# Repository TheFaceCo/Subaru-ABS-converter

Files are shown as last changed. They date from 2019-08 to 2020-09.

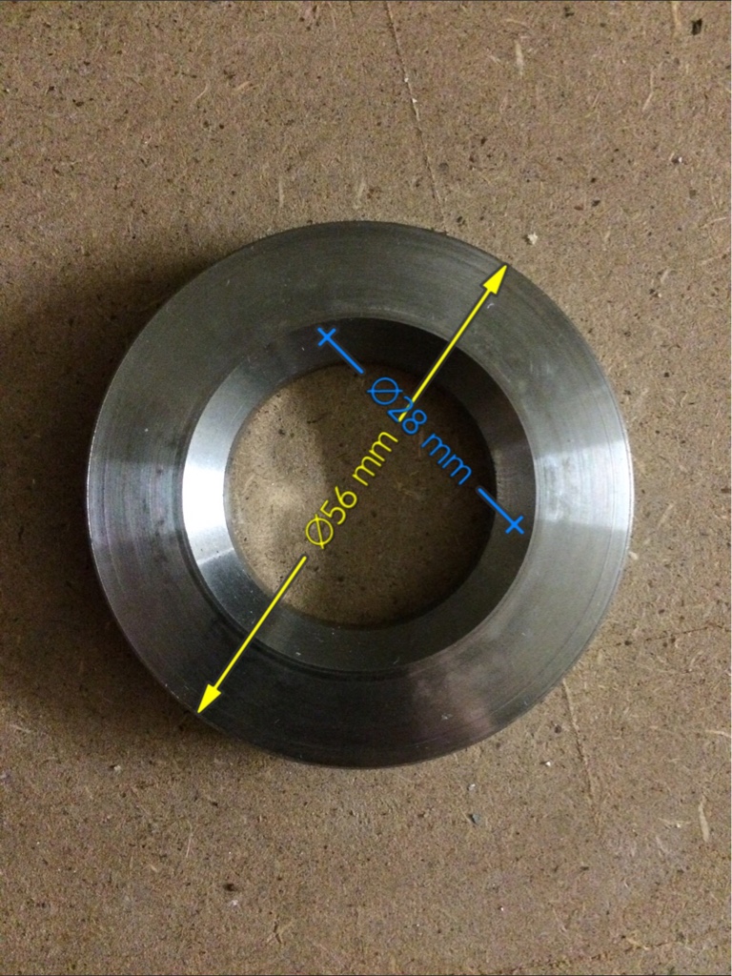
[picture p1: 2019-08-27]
Docs/e455d0daeaaa72b5a07195fe7253229a.jpg

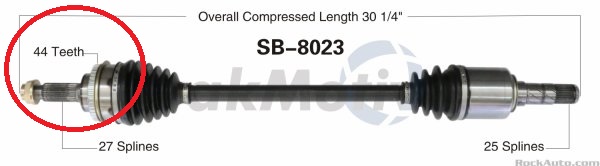
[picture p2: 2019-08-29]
Docs/SB-8023__ra_p.jpg

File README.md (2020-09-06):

# Subaru-ABS-converter
Read hall sensors, output variable reluctance (VR) sensors.

This converts modern hall sensor inputs to older VR outputs using a Maxim 9921 IC to read 2-wire hall sensors with a Teensy 3.2. 
Use this device if you are installing new hubs that use hall wheel speed sensors on old cars with variable reluctance ABS tone-rings.

The output stage is a 2-bit digital output fed to an audio transformer (1:1 600ohm:600ohm). 
The transformer removes the DC bias and presents an inductive source to the OEM ABS inputs (to circumvent open- or short-circuit error detection).

Set the input wheel tooth count to the OEM VR wheel tooth count. 

Set the output wheel tooth count to 2x the number of magnetic poles (count poles using magentic film, see image of subaru encoder). 
The Max9921 counts both the rising and falling edge of each magnetic pole, hence the multiplier.

Set Teensy clock to 24MHz to reduce thermal issues. CPU may freeze at high temperatures. First suspect for stability problems is the crystal oscillator. 

This also includes a generic digital output labeled "VSS". This allows the device to present a VSS signal calculated as the average of both inputs.
The VSS output can be used to provide a VSS signal in the case of a new transmission without a built-in VSS sensor.
The VSS output, as installed in my car, just drives an LED and is used for status reporting. This needs to be modified if you want a proper VSS output.

There is an additional op-amp stage, but this has been left un-routed due to pure laziness. 

This setup produces and unknown amount of jitter, but it should be relatively small. 

Outputs will be disabled by >1 error per 10 seconds in the default config. 

Be sure to cut the USB power trace on the teensy prior to soldering to the board.

Use at your own risk.

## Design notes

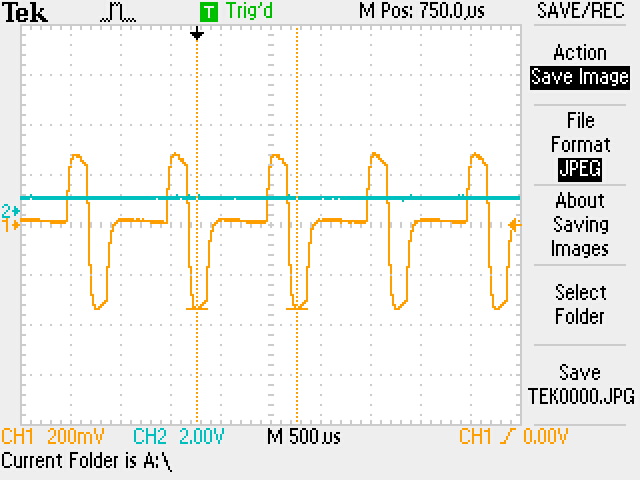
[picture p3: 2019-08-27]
Docs/TEK0000.JPG

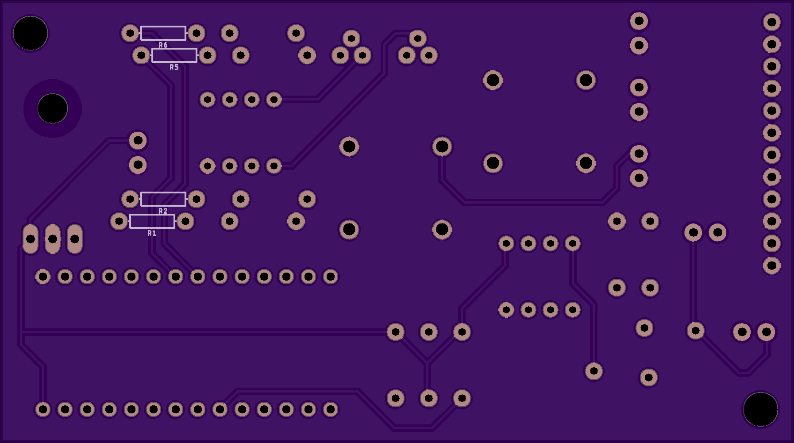
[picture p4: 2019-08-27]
Docs/f8dbdd23919a8299953b418dddf1daec.png

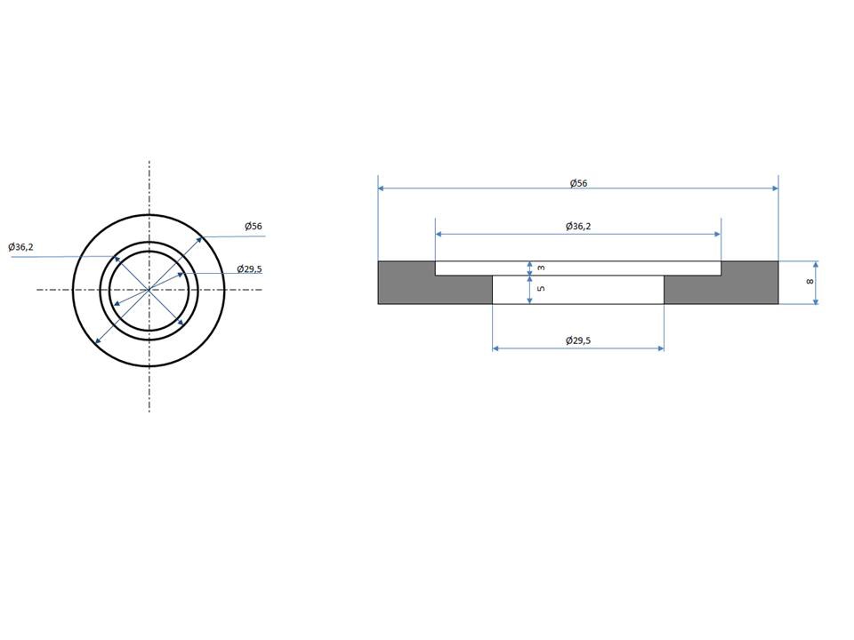
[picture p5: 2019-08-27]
Docs/axle spacer.jpg

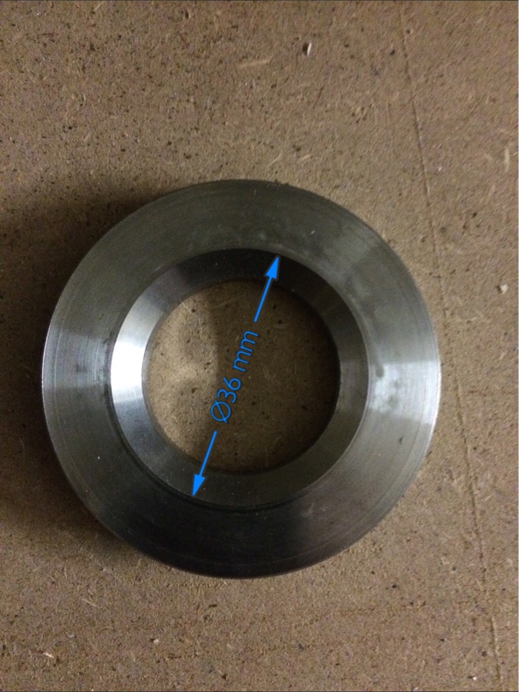
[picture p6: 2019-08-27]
Docs/8fbcc94c7023e025b707d7941de25b55.jpg

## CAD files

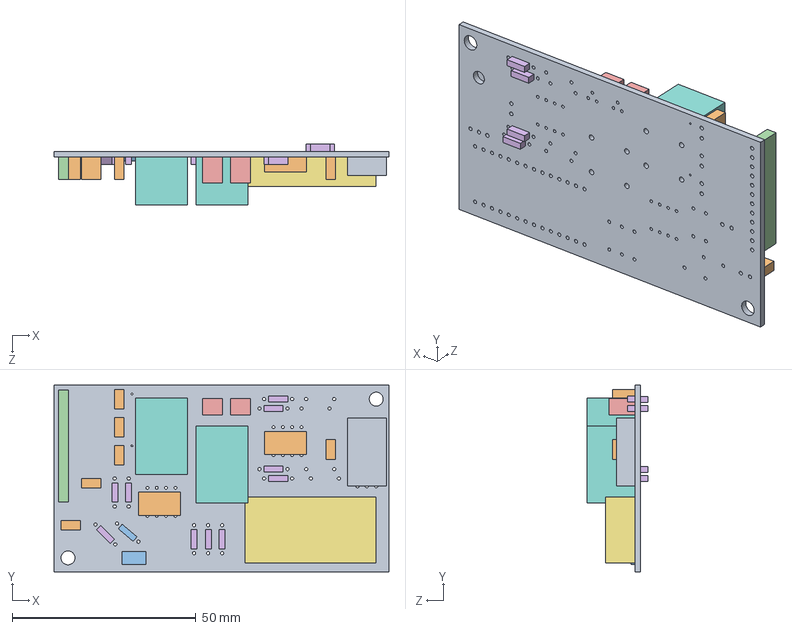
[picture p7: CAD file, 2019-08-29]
Layout/CAD/abs converter.SLDASM
91.1 x 50.8 x 16.6 mm
abs converter
CAPPTHSMALLKIT_0_1UF x 6
DIODE1N4148_200MA_100V_1V
1X12_J1_1X12
TO92_600MA_40V x 2
AXIAL0_3_10K x 14
TEENSY_3_03_2_LC_DIL_TEENSY_3_13_2_DIL
TRANSFORMER_TRANSFORMERPTH x 2
TO220ALT_U1_TO220ALT
DIP08_LM358 x 2
210061L_MAX9921AUB_

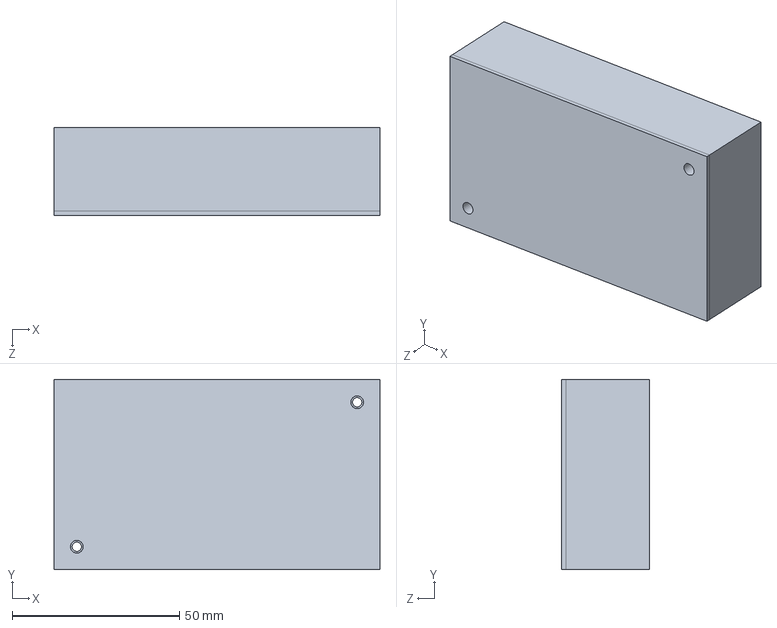
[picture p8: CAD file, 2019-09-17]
Layout/abs converter sw.SLDPRT
97.4 x 56.8 x 26.2 mm

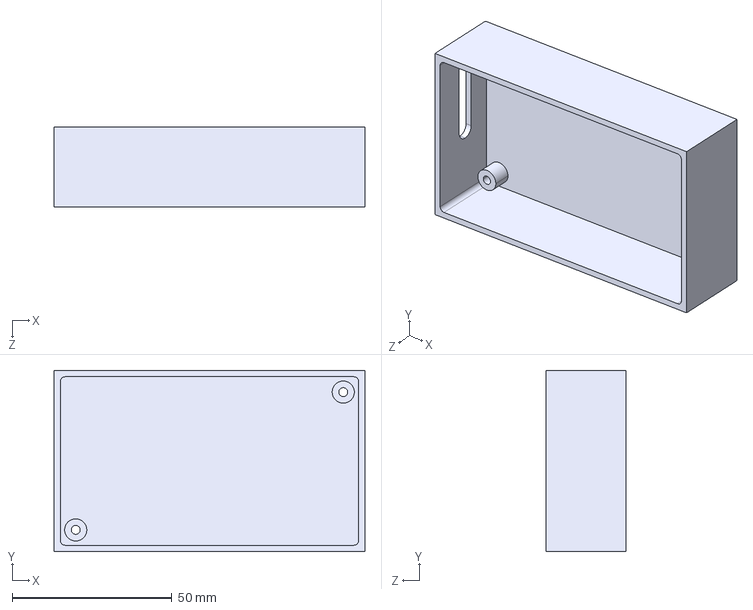
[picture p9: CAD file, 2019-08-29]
Layout/abs converter sw-Boss-Extrude2.STEP
97.4 x 56.8 x 25.0 mm

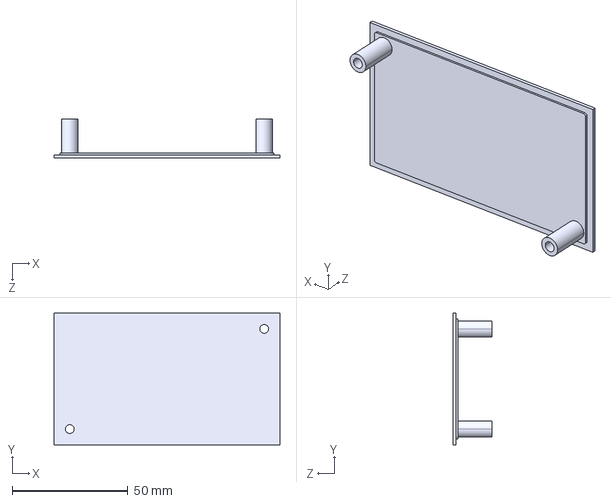
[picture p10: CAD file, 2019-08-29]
Layout/abs converter sw-Boss-Extrude4.STEP
97.4 x 56.8 x 16.7 mm

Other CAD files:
Layout/abs converter sw-Boss-Extrude2.SLDPRT
Layout/abs converter sw-Boss-Extrude2.STL
Layout/abs converter sw-Boss-Extrude4.SLDPRT
Layout/abs converter sw-Boss-Extrude4.STL

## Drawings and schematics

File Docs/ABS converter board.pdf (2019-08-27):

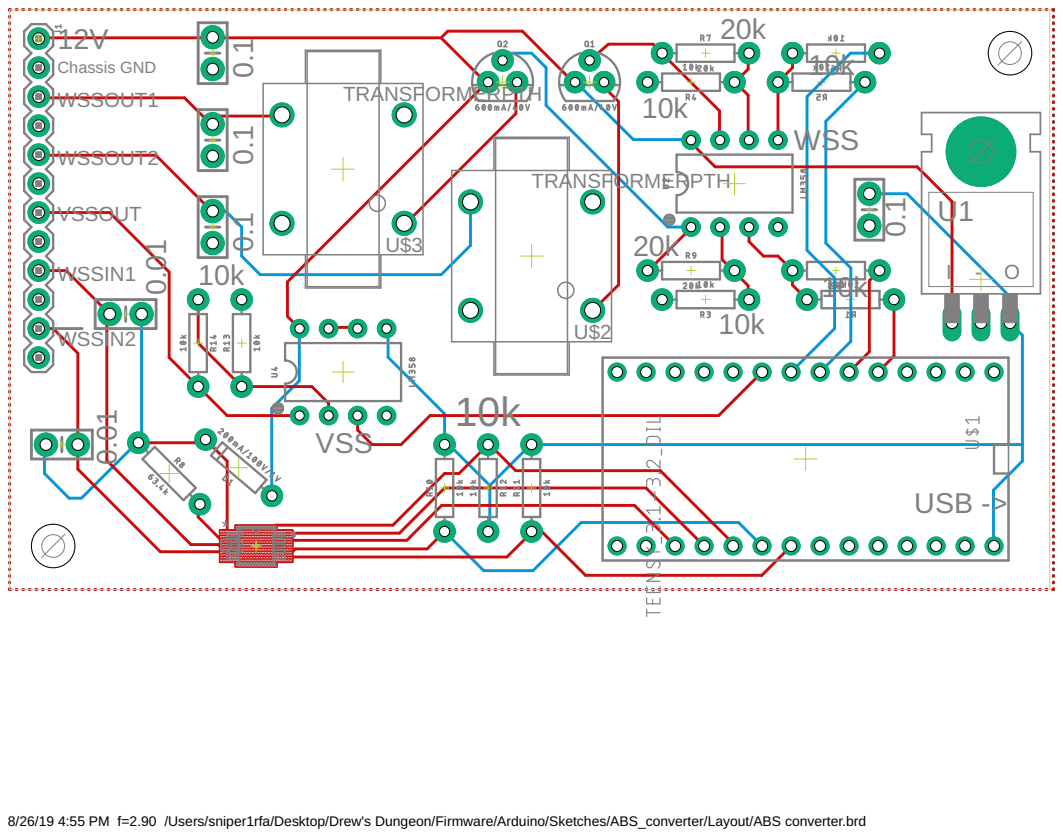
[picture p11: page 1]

8/26/19 4:55 PM f=2.90 /Users/sniper1rfa/Desktop/Drew's Dungeon/Firmware/Arduino/Sketches/ABS_converter/Layout/ABS converter.brd

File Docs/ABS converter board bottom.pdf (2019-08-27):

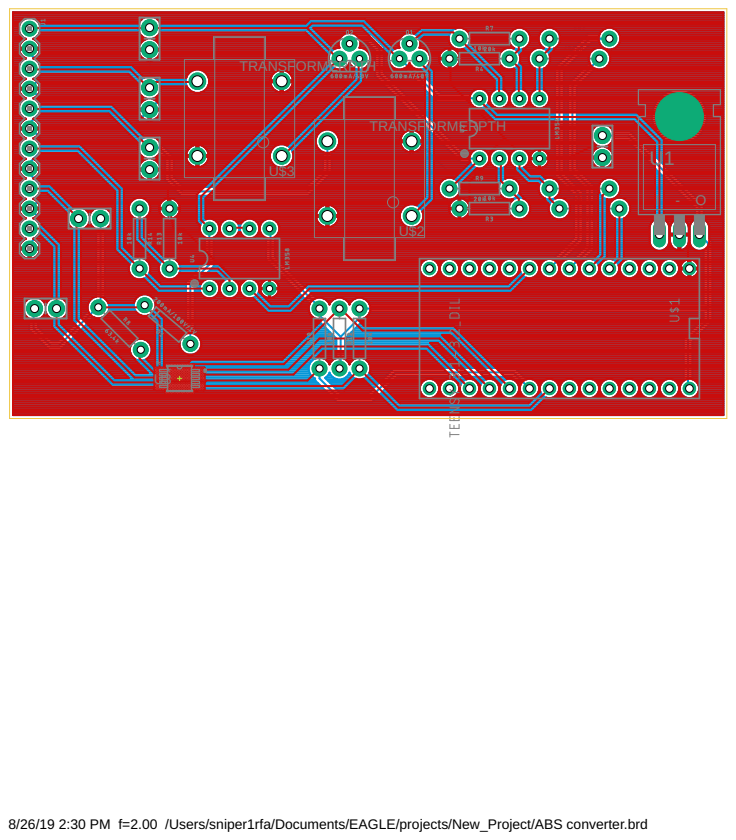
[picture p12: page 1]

8/26/19 2:30 PM f=2.00 /Users/sniper1rfa/Documents/EAGLE/projects/New_Project/ABS converter.brd

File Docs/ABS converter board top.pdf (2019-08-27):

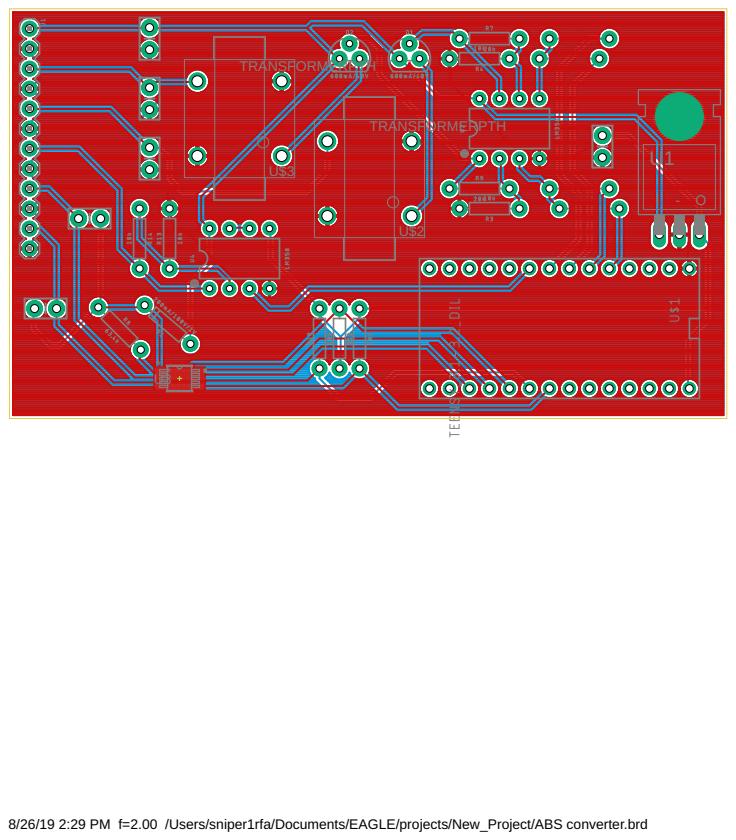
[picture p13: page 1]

8/26/19 2:29 PM f=2.00 /Users/sniper1rfa/Documents/EAGLE/projects/New_Project/ABS converter.brd

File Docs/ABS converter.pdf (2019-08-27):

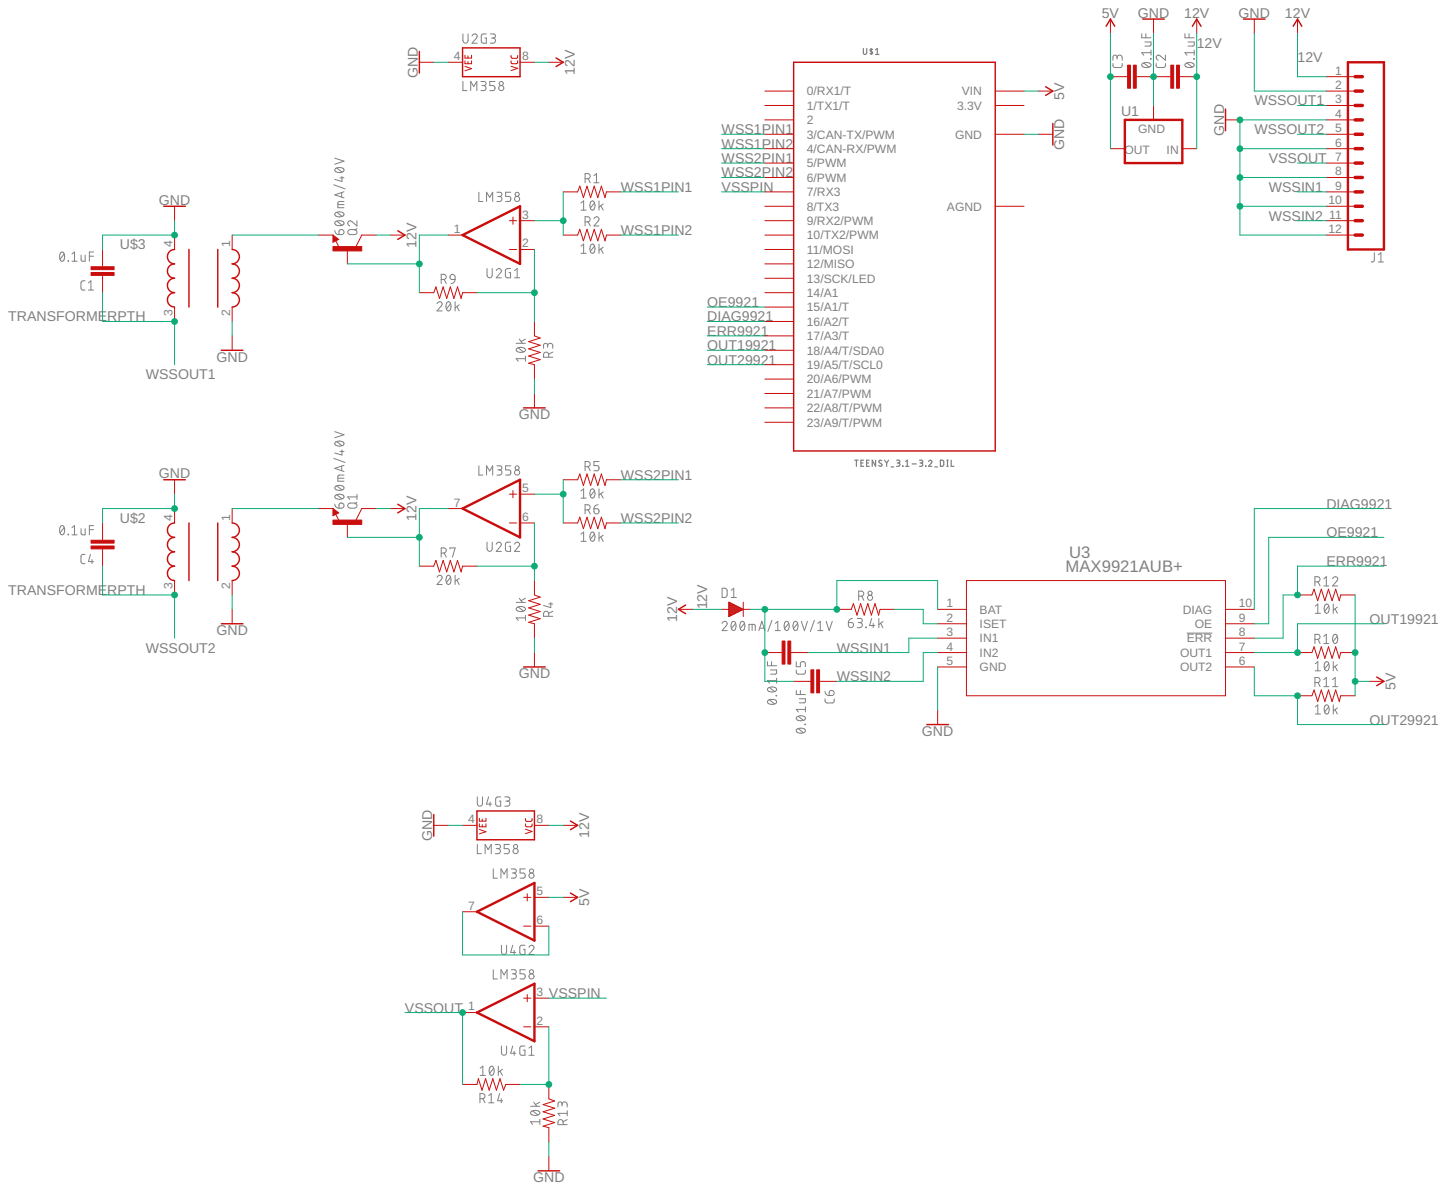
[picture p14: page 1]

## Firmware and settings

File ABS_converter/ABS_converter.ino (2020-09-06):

#define debug1 0 //enable serial output of pulse count data from input 1
#define debug2 0 //input 2
#define debugout1 0 //output1
#define debugout2 0 //output2
unsigned int debugincount1 = 0; //used for counting input pulses (debug output shows #counts since start. Wraps to 0 at 64k
unsigned int debugoutcount1 = 0;
unsigned int debugincount2 = 0;
unsigned int debugoutcount2 = 0;

#define VSSoutput 0 //set to one for output to run as VSS. Set to 0 for use as GPIO. Default is temporarily showing an average of both WSS sensors with an LED.
#define VSSlightoff 0 //how long (number of blinks) to display VSS on output when VSS is disabled

//Defined as const variables to ensure type, to prevent speed problems with type conversions
const unsigned long inputwheelteeth = 96; //Encoder has 48 N and 48 S poles. The max9921 sees each as 1 or 0, and "no magnet" is an indeterminate state.
const unsigned long outputwheelteeth = 44;
const unsigned long VSSwheelteeth = 1; //this number is made up. Set to correct wheel count from transmission

#define WSS1PIN1  3
#define WSS1PIN2  4
#define WSS2PIN1  5
#define WSS2PIN2  6
#define VSSPIN    7
#define OE9921    15
#define DIAG9921  16
#define ERR9921   17
#define OUT19921  18
#define OUT29921  19
#define ONBOARDLED 13

unsigned long halfwave = 300; //used to determined the shape of the output pulse
#define longhalfwave  300 //seems like ideally the waveform should be about 600uS long, but that needs to scale down at higher speeds.

#define minimumspeed 1000 //originally used to set a floor to the WSS outputs. Doesn't seem to be required, left for posterity. 

const unsigned long complement1 = 70; // Used as a running average of two input periods. Must add to exactly 100. int to avoid float math
const unsigned long complement2 = 30;

unsigned long period1 = 100;
unsigned long periodflag1;
unsigned long delayflag1;
unsigned long signal1start;
unsigned long signal1send;
unsigned long signal1end;
unsigned long periodtimer1;
unsigned long microsISRbuffer1;
unsigned long period1buffer;
unsigned long oldperiod1buffer;

unsigned long period2 = 100;
unsigned long periodflag2;
unsigned long delayflag2;
unsigned long signal2start;
unsigned long signal2send;
unsigned long signal2end;
unsigned long periodtimer2;
unsigned long microsISRbuffer2;
unsigned long period2buffer;
unsigned long oldperiod2buffer;

unsigned long VSSfactor1;
unsigned long VSSfactor2;
unsigned long VSSperiodbuffer;
unsigned long VSSperiod = 10000000;
unsigned long VSSperiodtimer;
unsigned long VSSdelayflag;
unsigned long VSSlightcount = 0;

bool signal1started = false; //these are used to find the start, middle, and end of the output waveform.
bool signal1sent = false;
bool signal1ended = false;

bool signal2started = false;
bool signal2sent = false;
bool signal2ended = false;

bool input1found = false; //ISR flags
bool input2found = false;

bool VSStoggle = false; //VSS output toggles high/low every half period

bool enabled = false; //output is not enabled until the first input pulse is found.
bool disabled = false; // used to manually kill output
bool error = false; //

int errreport = 0;
bool ERRstatus;
bool OUT1status;
bool OUT2status;

bool errortimer = false;
unsigned long AcceptableErrorPeriod = 10000;
unsigned long ErrorPeriodFlag;

void setup() {
  // put your setup code here, to run once:
  //  if (debug1 || debug2 || debugout1 || debugout2) {
  Serial.begin(115200);
  delay(2000);
  Serial.println("ABS Converter");
  Serial.print("Input 1 debug: ");
  Serial.println(debug1);
  Serial.print("Input 2 debug: ");
  Serial.println(debug2);
  Serial.print("Output 1 debug: ");
  Serial.println(debugout1);
  Serial.print("Output 2 debug: ");
  Serial.println(debugout2);

  //  }
  //wheelspeed outputs use two output pins through a voltage divider for 0, 1.75, and 3v (00, 01, and 11)
  pinMode(WSS1PIN1, OUTPUT); //wheelspeed 1 output 1
  pinMode(WSS1PIN2, OUTPUT); //wheelspeed 1 output 2
  pinMode(WSS2PIN1, OUTPUT);//wheelspeed 2 output 1
  pinMode(WSS2PIN2, OUTPUT);//wheelspeed 2 output 2

  pinMode(VSSPIN, OUTPUT);//VSS output
  pinMode(OE9921, OUTPUT);//Output enable to MAX9921
  pinMode(DIAG9921, OUTPUT);//Diag to MAX9921
  pinMode(ERR9921, INPUT); //ERR from MAX9921
  pinMode(OUT19921, INPUT); //Hall 1 signal from MAX9921
  pinMode(OUT29921, INPUT); //Hall 2 signal from MAX9921

  pinMode(ONBOARDLED, OUTPUT); //onboard LED to display power
  digitalWriteFast(ONBOARDLED, HIGH); //display power state

  digitalWriteFast(DIAG9921, LOW); //enforce DIAG port state

  delay(10); //give the max some time to get ready.
  digitalWriteFast(OE9921, HIGH); //enable max9921
  delay(10);

  Serial.println("Max9921 enabled");

  attachInterrupt(digitalPinToInterrupt(OUT19921), input1ISR, CHANGE); //count rising and falling edges of Max9921 outputs.
  attachInterrupt(digitalPinToInterrupt(OUT29921), input2ISR, CHANGE);
  attachInterrupt(digitalPinToInterrupt(ERR9921), ERRISR, FALLING);

  delayflag1 = micros(); //sets up initial conditions for WSS output waveform
  periodflag1 = delayflag1; //avoid second call to micros(), trickrepeated throughout
  signal1send = period1 - halfwave;
  signal1end = period1;
  signal1start = signal1send - halfwave;

  delayflag2 = delayflag1;
  periodflag2 = delayflag1;
  signal2send = period2 - halfwave;
  signal2end = period2;
  signal2start = signal2send - halfwave;

  VSSdelayflag = delayflag1;

  digitalWriteFast(WSS1PIN1, HIGH);
  digitalWriteFast(WSS1PIN2, LOW);
  digitalWriteFast(WSS2PIN1, HIGH);
  digitalWriteFast(WSS2PIN2, LOW);
  digitalWriteFast(VSSPIN, HIGH);

  updateVSS();

}

void loop() {
  periodtimer1 = micros();
  periodtimer2 = periodtimer1;
  VSSperiodtimer = periodtimer1;
  if (!disabled) {
    if (enabled) {
      if (input1found) {
        if (debug1) {
          debugincount1++;
          Serial.print("in1: ");
          Serial.println(debugincount1);
        }
        period1buffer = microsISRbuffer1 - periodflag1; //calculate elapsed time since last ISR event
        periodflag1 = microsISRbuffer1; //set flag to 'current' time from ISR

        period1buffer = period1buffer * inputwheelteeth; //scale period up by input wheel count

        VSSfactor1 = period1buffer; //store scaled period for VSS

        period1buffer = period1buffer / outputwheelteeth; //scale period down by output wheel count

        period1buffer = period1buffer * complement1; //store period with filter
        oldperiod1buffer = period1;
        oldperiod1buffer = oldperiod1buffer * complement2;
        period1buffer = oldperiod1buffer + period1buffer;
        period1buffer = period1buffer / 100;

        input1found = false;
        updateVSS();

        if (period1buffer < 2 * longhalfwave + 50) { //scale waveform dynamically from longest wavelength as speed increases
          halfwave = period1buffer - 50;
          halfwave = halfwave / 2;
        }
        else {
          halfwave = longhalfwave;
        }

        //period1 = period1buffer; //store scaled period directly without filtering

        if (!signal1started) {
          period1 = period1buffer;
          signal1start = period1 - (2 * halfwave); //backdate period to beginning of waveform
        }
      }

      if (input2found) {
        if (debug2) {
          debugincount2++;
          Serial.print("in2: ");
          Serial.println(debugincount2);
        }
        period2buffer = microsISRbuffer2 - periodflag2;
        periodflag2 = microsISRbuffer2;

        period2buffer = period2buffer * inputwheelteeth;

        VSSfactor2 = period2buffer;

        period2buffer = period2buffer / outputwheelteeth;

        period2buffer = period2buffer * complement1;
        oldperiod2buffer = period2;
        oldperiod2buffer = oldperiod2buffer * complement2;
        period2buffer = oldperiod2buffer + period2buffer;
        period2buffer = period2buffer / 100;

        input2found = false;
        updateVSS();

        if (period2buffer < 2 * longhalfwave + 50) {
          halfwave = period2buffer - 50;
          halfwave = halfwave / 2;
        }
        else {
          halfwave = longhalfwave;
        }

        //period2 = period2buffer; //removed filter

        //end of signal occurs when the output stage is returned to neutral (1 output HIGH, one output LOW). The prior event it the zero crossing (outputs both LOW). The next prior event is the start of the wave (both outputs HIGH)
        if (!signal2started) {
          period2 = period2buffer; //store new value into active variable only between pulses.
          signal2start = period2 - (2 * halfwave); //backdate period to beginning of waveform
        }
      }

      //generate waveform for output 1
      //    if (period1 > minimumspeed) {
      if (periodtimer1 - delayflag1 >= signal1start) {
        if (!signal1started) {
          digitalWriteFast(WSS1PIN1, LOW);
          digitalWriteFast(WSS1PIN2, LOW);
          signal1started = true;
          signal1send = signal1start + halfwave; //re-find zero crossing center in order to tolerate rapidly changing periods. If this is preloaded, signal distortion will result when the period is updated at a bad time.
          signal1end = signal1send + halfwave; //re-find waveform end (should correspond to the period on average)
        }
        if (!signal1sent) {
          if (periodtimer1 - delayflag1 >= signal1send) {
            digitalWriteFast(WSS1PIN1, HIGH);
            digitalWriteFast(WSS1PIN2, HIGH);
            signal1sent = true;
            signal1ended = false;
          }
        }
        if (!signal1ended) {
          if (periodtimer1 - delayflag1 >= signal1end) {
            digitalWriteFast(WSS1PIN1, HIGH);
            digitalWriteFast(WSS1PIN2, LOW);
            delayflag1 = periodtimer1;
            signal1ended = true;
            signal1started = false;
            signal1sent = false;
            if (debugout1) {
              debugoutcount1++;
              Serial.print("out1: ");
              Serial.println(debugoutcount1);
            }
          }
        }
      }
      //    }
      //    else {
      //      digitalWriteFast(WSS1PIN1, HIGH);
      //      digitalWriteFast(WSS1PIN2, LOW);
      //      delayflag1 = periodtimer1;
      //      signal1ended = true;
      //      signal1started = false;
      //      signal1sent = false;
      //    }

      //generate waveform for output 2
      //    if (period2 > minimumspeed) {
      if (periodtimer2 - delayflag2 >= signal2start) {
        if (!signal2started) {
          digitalWriteFast(WSS2PIN1, LOW);
          digitalWriteFast(WSS2PIN2, LOW);
          signal2started = true;
          signal2send = signal2start + halfwave; //re-find zero crossing center in order to tolerate rapidly changing periods. If this is preloaded, signal distortion will result when the period is updated at a bad time.
          signal2end = signal2send + halfwave; //re-find waveform end (should correspond to the period on average)
        }
        if (!signal2sent) {
          if (periodtimer2 - delayflag2 >= signal2send) {
            digitalWriteFast(WSS2PIN1, HIGH);
            digitalWriteFast(WSS2PIN2, HIGH);
            signal2sent = true;
            signal2ended = false;
          }
        }
        if (!signal2ended) {
          if (periodtimer2 - delayflag2 >= signal2end) {
            digitalWriteFast(WSS2PIN1, HIGH);
            digitalWriteFast(WSS2PIN2, LOW);
            delayflag2 = periodtimer2;
            signal2ended = true;
            signal2started = false;
            signal2sent = false;
            if (debugout2) {
              debugoutcount2++;
              Serial.print("out2: ");
              Serial.println(debugoutcount2);
            }
          }
        }
      }
      //    }
      //    else {
      //      digitalWriteFast(WSS2PIN1, HIGH);
      //      digitalWriteFast(WSS2PIN2, LOW);
      //      delayflag2 = periodtimer2;
      //      signal2ended = true;
      //      signal2started = false;
      //      signal2sent = false;
      //    }

      //generate waveform for VSS
      if (VSSlightcount < VSSlightoff) { //This line is used to disable the VSS output after a short period, because the VSS output was originally used to verify everything was working via an LED.
        if (VSSperiodtimer - VSSdelayflag >= VSSperiod) {
          if (VSStoggle) {
            digitalWriteFast(VSSPIN, HIGH);
            VSStoggle = !VSStoggle;
            if (!VSSoutput) {
              VSSlightcount++;
            }
          }
          else {
            digitalWriteFast(VSSPIN, LOW);
            VSStoggle = !VSStoggle;
          }
          VSSdelayflag = VSSperiodtimer;
        }
      }
    }
  }
  if (error) {
    ErrorPeriodFlag = millis(); //Start timing between errors.
    errreport++; //count errors
    errortimer = true;
    Serial.println("Error reported by Max9921");
    Serial.print("Err pin: ");
    Serial.println(ERRstatus);
    Serial.print("Hall 1: ");
    Serial.println(OUT1status);
    Serial.print("Hall 2: ");
    Serial.println(OUT2status); //refer to diagnostic table in Max9921 documentation.
    if (!VSSoutput) {
      digitalWriteFast(VSSPIN, LOW); //turn the LED on if VSS is used for error reporting
    }
    error = false; //clear error flag
  }

  if (errortimer) {
    if (millis() - ErrorPeriodFlag >= AcceptableErrorPeriod) {
      errreport = 0; //if more than 10 seconds has elapsed between errors, reset counter to 0
      if (!VSSoutput) {
        digitalWriteFast(VSSPIN, HIGH); //turn the LED off if VSS is used for error reporting.
      }
      errortimer = false;
    }
  }
  if (errreport > 1) { //if more than 1 error has been encountered in 10 seconds disable outputs and write error out to LED connected to VSS pin.
    detachInterrupt(digitalPinToInterrupt(ERR9921));
    disabled = true; //
    if (!VSSoutput) { //if the VSS pin is used for a status LED, use it to blink the most recent error reported by Max9921. One blink = 0, two blinks = 1
      for (int i = 0; i <= 5; i++) {
        digitalWriteFast(VSSPIN, HIGH);
        delay(4000);
        if (ERRstatus) {
          digitalWriteFast(VSSPIN, LOW);
          delay(100);
          digitalWriteFast(VSSPIN, HIGH);
          delay(100);
          digitalWriteFast(VSSPIN, LOW);
          delay(100);
          digitalWriteFast(VSSPIN, HIGH);
          delay(1000);
        }
        else {
          digitalWriteFast(VSSPIN, LOW);
          delay(100);
          digitalWriteFast(VSSPIN, HIGH);
          delay(1000);
        }
        if (OUT1status) {
          digitalWriteFast(VSSPIN, LOW);
          delay(100);
          digitalWriteFast(VSSPIN, HIGH);
          delay(100);
          digitalWriteFast(VSSPIN, LOW);
          delay(100);
          digitalWriteFast(VSSPIN, HIGH);
          delay(1000);
        }
        else {
          digitalWriteFast(VSSPIN, LOW);
          delay(100);
          digitalWriteFast(VSSPIN, HIGH);
          delay(1000);
        }
        if (OUT2status) {
          digitalWriteFast(VSSPIN, LOW);
          delay(100);
          digitalWriteFast(VSSPIN, HIGH);
          delay(100);
          digitalWriteFast(VSSPIN, LOW);
          delay(100);
          digitalWriteFast(VSSPIN, HIGH);
          delay(1000);
        }
        else {
          digitalWriteFast(VSSPIN, LOW);
          delay(100);
          digitalWriteFast(VSSPIN, HIGH);
          delay(1000);
        }
      }
    }
  }
}

void input1ISR() {
  microsISRbuffer1 = micros();
  enabled = true;
  input1found = true; //set a flag to indicate that the ISR has been accessed
}

void input2ISR() {
  microsISRbuffer2 = micros();
  enabled = true;
  input2found = true; //set a flag to indicate that the ISR has been accessed
}

void ERRISR() {
  digitalWriteFast(DIAG9921, HIGH); //drive diagnostic pin high to retreive diagnostic info. See truth table in Max9921 documentation. IN1 faults mask IN2 faults. Faults are transient (not latched), so this must be fast.
  delayMicroseconds(1); //allow a bit of time for error output. 350ns according to Max9921 documentation. This probably isn't required, but it's hard to say.
  ERRstatus = digitalReadFast(ERR9921); //Retrieve pin status
  OUT1status = digitalReadFast(OUT19921);
  OUT2status = digitalReadFast(OUT29921);
  digitalWriteFast(DIAG9921, LOW); //drive diagnostic pin low to reset faulted sensor.
  error = true;
}

void updateVSS() {
  VSSperiodbuffer = VSSfactor1 + VSSfactor2;
  VSSperiodbuffer = VSSperiodbuffer / 2; //take the average of the two wheel speed sensors
  VSSperiodbuffer = VSSperiodbuffer / VSSwheelteeth;

  VSSperiodbuffer = VSSperiodbuffer * complement1; // filter VSS
  VSSperiod = VSSperiod * complement2;
  VSSperiod = VSSperiod + VSSperiodbuffer;
  VSSperiod = VSSperiod / 200; //divide by 200 instead of 100 because we'll be toggling VSS on or off every half period

  // VSSperiod = VSSperiodbuffer / 2; without filter

}

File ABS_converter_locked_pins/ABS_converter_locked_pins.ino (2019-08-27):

unsigned long period = 1000;
unsigned long halfwave = 200;
unsigned long periodflag1;
unsigned long delayflag1;
unsigned long signalstart;
unsigned long signalsend;
unsigned long signalend;
unsigned long periodtimer1;


bool signalstarted = false;
bool signalsent = false;
bool signalended = false;

void setup() {
  // put your setup code here, to run once:
  pinMode(11, OUTPUT);
  pinMode(12, OUTPUT);
  pinMode(13, OUTPUT);//output enable to MAX9921
  pinMode(14, INPUT); //Hall 1 signal from MAX9921
  pinMode(15, INPUT); //Hall 2
  digitalWriteFast(13, LOW);
  attachInterrupt(digitalPinToInterrupt(14), input1ISR, RISING);
  delayflag1 = micros();
  periodflag1 = micros();
  signalsend = period - halfwave;
  signalend = period;
  signalstart = signalsend - halfwave;
  
}

void loop() {
//  periodtimer1 = micros();
//  
//  if (periodtimer1 - delayflag1 >= signalstart) {
//    if (!signalstarted) {
//      digitalWriteFast(11, HIGH);
//      digitalWriteFast(12, HIGH);
//      signalstarted = true;
//    }
//    if (!signalsent) {
//      if (periodtimer1 - delayflag1 >= signalsend) {
//        digitalWriteFast(11, LOW);
//        digitalWriteFast(12, LOW);
//        signalsent = true;
//        signalended = false;
//      }
//    }
//    if (!signalended) {
//      if (periodtimer1 - delayflag1 >= signalend) {
        digitalWriteFast(11, HIGH);
        digitalWriteFast(12, HIGH);
//        delayflag1 = periodtimer1;
//        signalended = true;
//        signalstarted = false;
//        signalsent = false;
//      }
//    }
//    // put your main code here, to run repeatedly:
//
//  }
}

void input1ISR() {
  period = micros() - periodflag1;
  periodflag1 = micros();
  signalsend = period - halfwave;
  signalend = period;
  signalstart = signalsend - halfwave;
}

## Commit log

2019-08-29 made a housing for it
    [abs converter sw-Boss-Extrude2.SLDPRT, abs converter sw-Boss-Extrude2.STEP, abs converter sw-Boss-Extrude2.STL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]
2019-08-31 added corrected tone ring tooth counts
    -
    [ABS_converter.ino]
2019-09-16 fixed resistor labels
    changes to common 22k from 20k on opamps. Added big label to 63.4k resistor for max9921 chip configuration.
2019-09-16 Updated for correct pinouts
    Added temporary VSS output. Split out inputs and outputs for L/R WSS.
    Added some more labels on board and moved them around for visibility when assembled.
    [ABS_converter.ino]
2019-09-17 removed input filter
    changed some other things that were inconsequential.
    ABS light goes off, but ABS is super sensitive, suggesting that the period conversion is wrong.
    [ABS_converter.ino]
2019-09-17 simplified slightly
    set a couple settings back to originals
2019-09-18 added back in the filter, block operation until a WSS sees an input.
2019-09-18 added minimum speed to outputs
    inverted output waveform
    [ABS_converter.ino]
2019-09-18 what the fuck
    inverted the tooth counts and the brakes work properly, but not with the number in the correct spot.
    [ABS_converter.ino]
2019-09-20 --- This seems to work ---
    set output tooth count to 88 (presumably there is a logic inverter to get a second pulse between teeth?).
    Seems sensitive to pulsewidth. 600uS seems like a happy medium - 400 uS seems to throw a light eventually and 750uS seems to throw a light quickly.
    Changed complements to 90/10 from 50/50. Changed light timeout to 2000 pulses.
    Could change to timeout at 300,000,000uS to get a 5 minute delay or 120,000,000 to get a 2 minute delay.
    Expect extreme jitter around 90mph with this code, due to the 600uS pulse running out of time (need 425uS pulsewidth at 120mph).
    [ABS_converter.ino]
2019-09-20 changed to do math all the time
    Does the period update at all times, but doesn't shunt the result into the active variable until it's outside the waveform.
    Compresses waveform to 400uS when period is less than 650uS.
    [ABS_converter.ino]
2019-09-20 changed to period variable scaling
    Changed from fixed period scaling to dynamic period scaling in order to keep wavelength as long as practicable. Scaling starts around 85mph (18.9 rev/s at 808 revs/mile)
    [ABS_converter.ino]
2019-09-20 figured out the math problem.
    the hall sensor is probably only reading every other encoder line, due to being a 2-wire hall sensor. Need to read up on how exactly they work.
    [ABS_converter.ino]
2019-09-20 fixed lack of explicit outpu on diag port
    [ABS_converter.ino]
2019-09-20 debug to verify count of 48 input teeth
    turns out alternating poles meants 96 on the magnet paper is 48 electrical.
2019-09-20 ISR's to 'change'
    The encoder alternates magnetic poles, and the max9921 interprets them as 1-0-1-0-etc. Both rising and falling edges are mechanically precise, and using both will reduce the output latency (since you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
    Filter changed to weight the previous value more heavily as a resut.
2019-09-20 Add VSS on/off selection, cleaned up variable definitions
    added filter back to VSS output.
2020-08-30 added diagnostic output to VSS pin
    As installed in my car, the VSS pin is being used to drive an LED. This outputs some diagnostics over the LED pin and serial.
2020-08-30 fixed delays in diag output
    [ABS_converter.ino]
2020-08-31 Improved error handling.
    Prior commits did not utilize the error or diagnostics pins on the Max, and any error would blank the outputs long enough to throw an ABS error at the ECU.
    New commit will automatically reset the Max9921 after reading an error. as quickly as possible (<2uS) Multiple fast errors (10s or less between errors) will disable the output and read out the error status on the VSS pin (if unused for vehicle speed). All errors are sent out on the serial bus.
    [ABS_converter.ino]
2020-08-31 Added "pending error" to output LED on VSS
    Will show a pending "CEL" (1 error in a ten second period). Clears after 10 seconds, unless another error is reported by the Max9921. If another error is found, the outputs are disabled and the last error is written out.
    Also cleaned up comments and bracketed all the "VSS as LED output" lines so they shut off if VSS is enabled.
    debug as unsigned int for predictable wrap behavior.
    [ABS_converter.ino]
2020-09-06 Added input filter cap to Max9921
    This should have been in there from the get-go. It will hold the max up during momentary brownouts.
    [ABS converter.brd]
